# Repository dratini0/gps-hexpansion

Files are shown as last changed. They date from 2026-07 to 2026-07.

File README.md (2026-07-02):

# GPS hexpansion

I came into posession of 95 surplous Ublox MAX-M10S GPS modules.
I just had to put some of them down on a hexpansion.

## Acknowledgements

Uses the [hexpansion template from EMF](https://github.com/emfcamp/badge-2024-hardware/tree/main/hexpansion)

I have attempted to maintain some pinout compatibility with [TechCabin's design](https://github.com/TechCabin/EMFBadge-Hexpansions-GPS), but it uses a very different chip.
Sorry for stepping on your toes!

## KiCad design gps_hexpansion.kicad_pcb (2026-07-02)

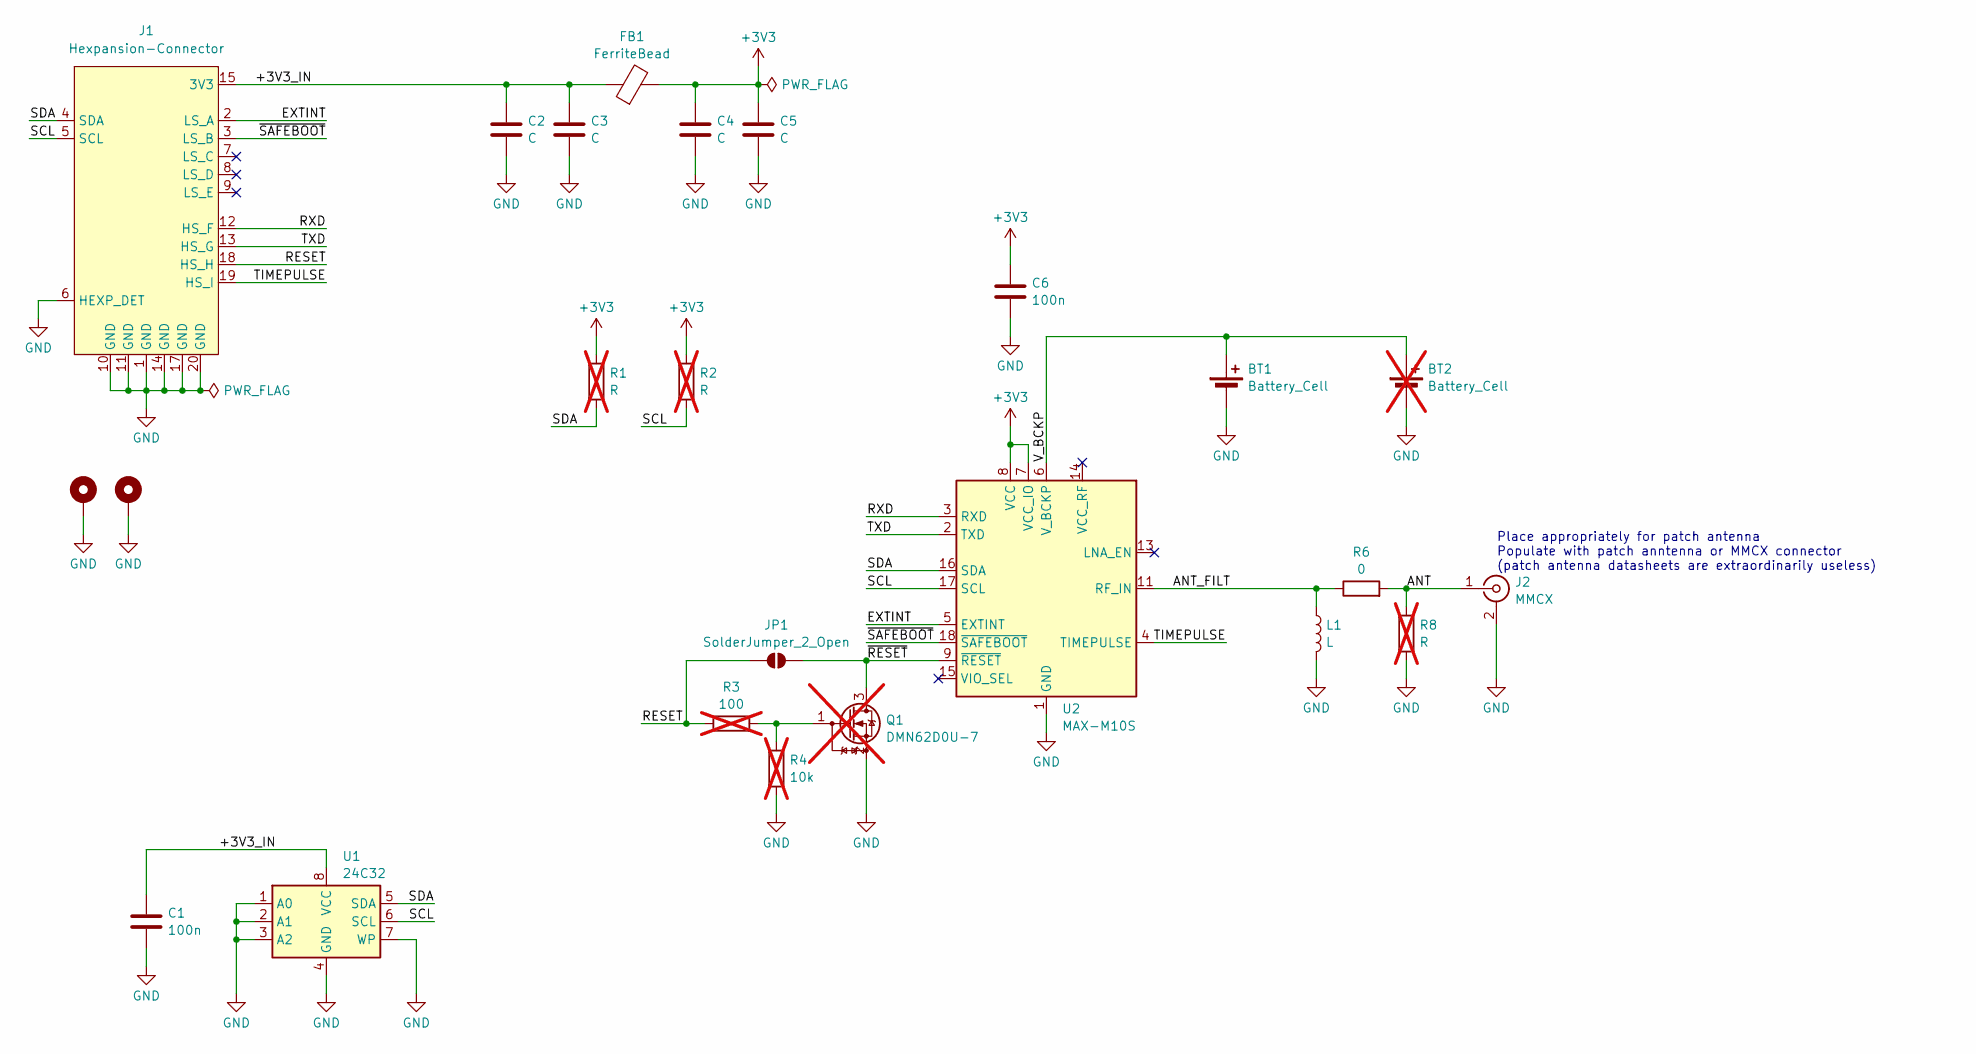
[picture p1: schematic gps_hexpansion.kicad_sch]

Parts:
BT1: Battery_Cell; card_edge_CR2032
BT2: Battery_Cell; BatteryHolder_Keystone_3000_1x12mm; not fitted
C1, C6: 100n; C_0805_2012Metric_Pad1.18x1.45mm_HandSolder
C2, C3, C4, C5: C; C_0805_2012Metric_Pad1.18x1.45mm_HandSolder
FB1: FerriteBead; L_0805_2012Metric_Pad1.05x1.20mm_HandSolder
H1, H2: MountingHole_Pad; MountingHole_2.2mm_M2_Pad_Via
J1: Hexpansion-Connector; hexpansion-edge-connector
J2: MMCX; MMCX_Molex_73415-1471_Vertical
JP1: SolderJumper_2_Open; SolderJumper-2_P1.3mm_Open_TrianglePad1.0x1.5mm
L1: L; L_0603_1608Metric
Q1: DMN62D0U-7; SOT-23; LCSC C151421; not fitted
R1, R2: R; R_0805_2012Metric_Pad1.20x1.40mm_HandSolder; not fitted
R3: 100; R_0805_2012Metric_Pad1.20x1.40mm_HandSolder; not fitted
R4: 10k; R_0805_2012Metric_Pad1.20x1.40mm_HandSolder; not fitted
R6: 0; R_0603_1608Metric
R8: R; R_0603_1608Metric; not fitted
U1: 24C32; SOIC-8_3.9x4.9mm_P1.27mm
U2: MAX-M10S; ublox_MAX

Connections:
+3V3: C4.1, C5.1, C6.1, FB1.2, R1.1, R2.1, U2.7 (VCC_IO), U2.8 (VCC)
/+3V3_IN: C1.1, C2.1, C3.1, FB1.1, J1.15 (3V3), J1.16 (3V3), U1.8 (VCC)
/ANT: J2.1 (In), R6.2, R8.2
/ANT_FILT: L1.1, R6.1, U2.11 (RF_IN)
/EXTINT: J1.2 (LS_A), U2.5 (EXTINT)
/RESET: J1.18 (HS_H), JP1.1 (A), R3.1
/RXD: J1.12 (HS_F), U2.3 (RXD)
/SCL: J1.5 (SCL), R2.2, U1.6 (SCL), U2.17 (SCL)
/SDA: J1.4 (SDA), R1.2, U1.5 (SDA), U2.16 (SDA)
/TIMEPULSE: J1.19 (HS_I), U2.4 (TIMEPULSE)
/TXD: J1.13 (HS_G), U2.2 (TXD)
/V_BCKP: BT1.1 (+), BT2.1 (+), U2.6 (V_BCKP)
/~RESET: JP1.2 (B), Q1.3 (D), U2.9 (~RESET)
/~SAFEBOOT: J1.3 (LS_B), U2.18 (~SAFEBOOT)
GND: BT1.2 (-), BT2.2 (-), C1.2, C2.2, C3.2, C4.2, C5.2, C6.2, H1.1, H2.1, J1.1 (GND), J1.6 (HEXP_DET), J1.10 (GND), J1.11 (GND), J1.14 (GND), J1.17 (GND), J1.20 (GND), J2.2 (Ext), L1.2, Q1.2 (S), R4.2, R8.1, U1.1 (A0), U1.2 (A1), U1.3 (A2), U1.4 (GND), U1.7 (WP), U2.1 (GND), U2.10 (GND), U2.12 (GND)
unnamed: Q1.1 (G), R3.2, R4.1

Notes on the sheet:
Place appropriately for patch antenna Populate with patch anntenna or MMCX connector (patch antenna datasheets are extraordinarily useless)

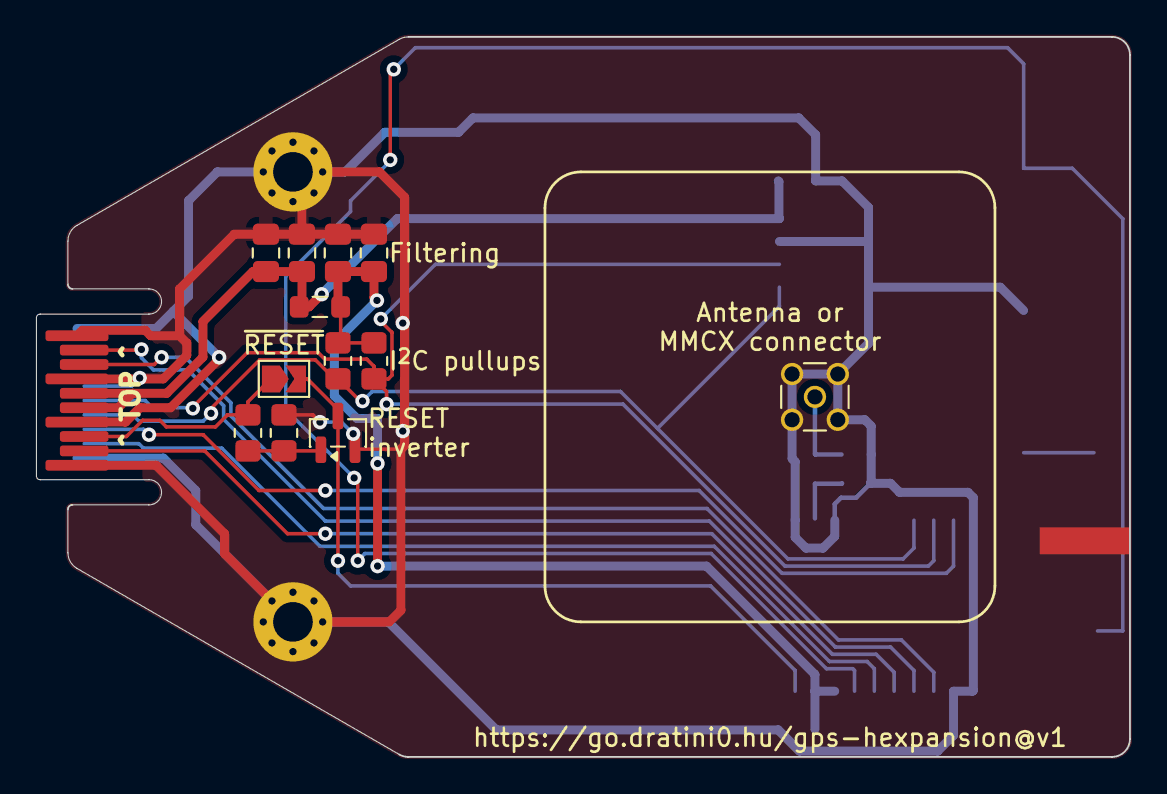
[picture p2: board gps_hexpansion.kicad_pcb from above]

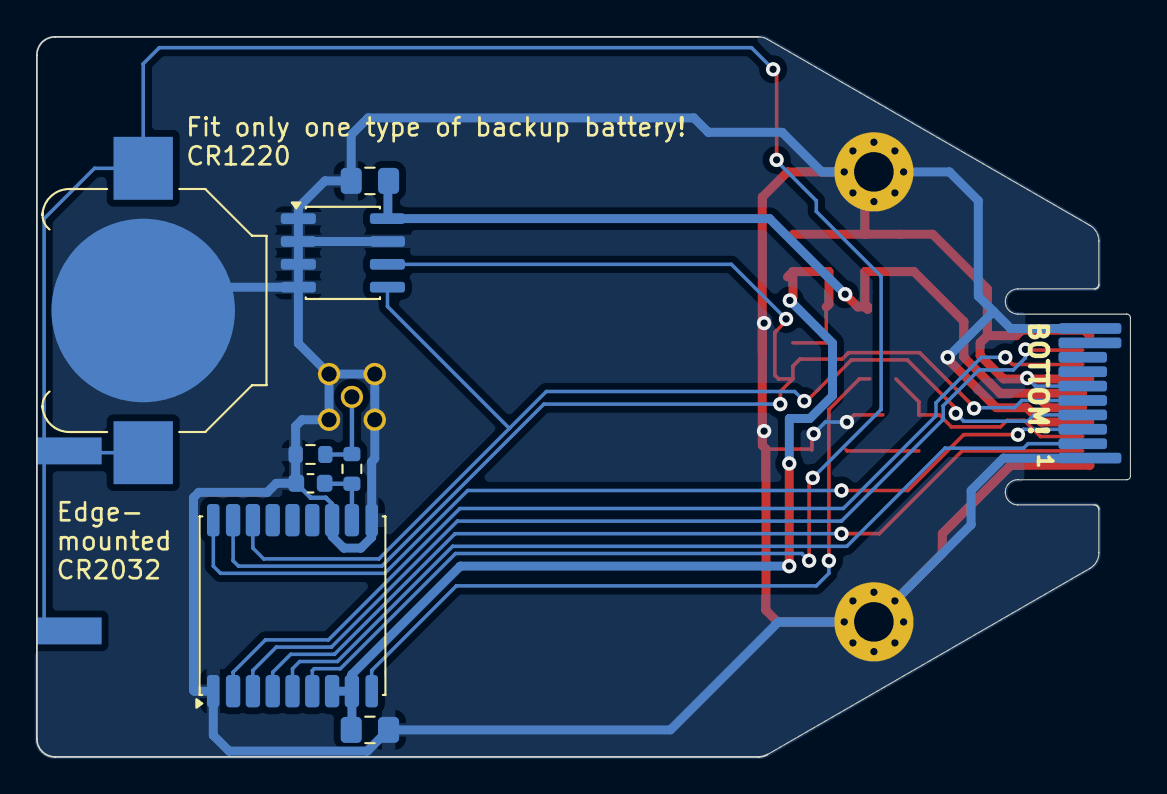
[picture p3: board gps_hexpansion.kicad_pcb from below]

Board: 2 copper layers, 60.8 x 40.0 mm, 24 parts (9 on the bottom side), 16 nets.

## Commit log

2026-07-02 v1, as sent to fab
    [gps_hexpansion.kicad_pcb, gps_hexpansion.kicad_sch]
2026-07-13 Update gitignore to ignore kicad locks
